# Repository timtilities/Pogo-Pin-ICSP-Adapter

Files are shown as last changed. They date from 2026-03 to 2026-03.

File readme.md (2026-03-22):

Pogo pin ICSP programming adapter

***

The standard 2x3 ICSP header that is usually used for Arduino/Atmel projects is bulky and requires a wide header on the PCB. For decent sized through-hole projects this may be OK, but I do a lot of SMD boards (much easier since you don't have to drill a bunch of holes).  I found lots of different ideas on the web, and decided to use pogo pins.  In addition, I found a great project that didn't require multiple PCBs to stabilize the pogo pins! Unfortunately, I don't remember who's project that was so I can't give them credit. Just keep in mind this idea was not entirely mine, nor is it unique. That being said, here are a couple pics of the raw PCB and the finished products:

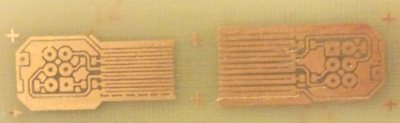
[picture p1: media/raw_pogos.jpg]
raw_pogos
 finished_pogos

There are 2 versions, the first being a "normal" sized board with a pitch of about 1.83mm, the second being a tiny version with a pitch of about 1.27mm. In most cases, I go with the 1.83 pitch board since I can route small traces between the pads. The 1.27mm version is good for those boards with no room to spare, but I have never needed it. The Kicad library only includes the larger 1.83mm pitch footprint. 

Here's an example of using the ICSP pads designed for these pogo adapters:

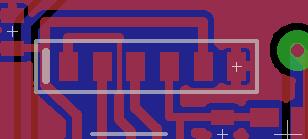
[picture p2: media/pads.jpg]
pads
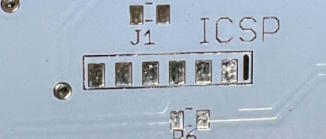
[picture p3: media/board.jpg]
board
 

To assemble the adapter, carefully solder the pogo pins in between the long PCB traces on the board. If done correctly, they should sit right in between the traces and be fairly stable while you solder.  I made the 2 pins on either end slightly longer than the middle pins, but it isn't really necessary.

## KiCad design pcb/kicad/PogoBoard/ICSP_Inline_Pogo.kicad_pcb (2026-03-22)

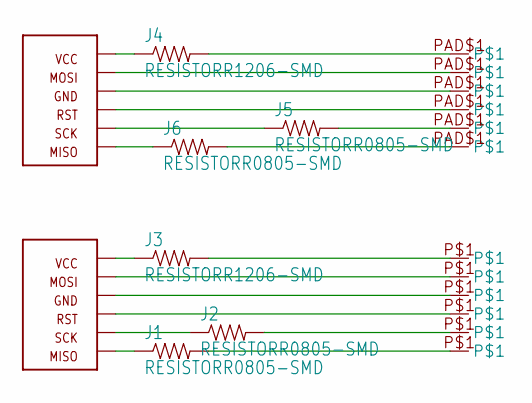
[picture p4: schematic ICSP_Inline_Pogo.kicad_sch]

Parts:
GND0: POGO_PADR50; P50_POGO_PIN
GND1: POGO_PADR75; P75_POGO_PIN
J1, J2, J5, J6: RESISTORR0805-SMD; R0805
J3, J4: RESISTORR1206-SMD; R1206
MISO0: POGO_PADR50; P50_POGO_PIN
MISO1: POGO_PADR75; P75_POGO_PIN
MOSI0: POGO_PADR50; P50_POGO_PIN
MOSI1: POGO_PADR75; P75_POGO_PIN
RST0: POGO_PADR50; P50_POGO_PIN
RST1: POGO_PADR75; P75_POGO_PIN
SCK0: POGO_PADR50; P50_POGO_PIN
SCK1: POGO_PADR75; P75_POGO_PIN
U$1, U$3: AVR_ICSP_6P2X3_THP; AVR_ICSP_2X3_THP
VCC0: POGO_PADR50; P50_POGO_PIN
VCC1: POGO_PADR75; P75_POGO_PIN

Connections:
GND: GND0.P$1, U$3.GND
GND1: GND1.PAD$1, U$1.GND
MISO: J1.1, U$3.MISO
MISO1: J6.2, MISO1.PAD$1
MOSI: MOSI0.P$1, U$3.MOSI
MOSI1: MOSI1.PAD$1, U$1.MOSI
unnamed: J1.2, MISO0.P$1
unnamed: J3.1, U$3.VCC
unnamed: J2.1, U$3.SCK
unnamed: J6.1, U$1.MISO
unnamed: J5.2, SCK1.PAD$1
unnamed: J4.1, U$1.VCC
RST: RST0.P$1, U$3.RST
RST1: RST1.PAD$1, U$1.RST
SCK: J2.2, SCK0.P$1
SCK1: J5.1, U$1.SCK
VCC: J3.2, VCC0.P$1
VCC1: J4.2, VCC1.PAD$1

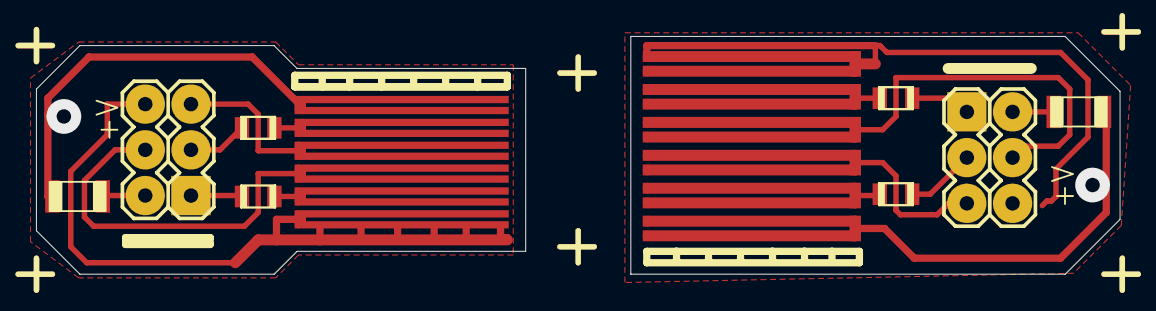
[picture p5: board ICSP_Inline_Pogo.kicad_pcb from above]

Board: 2 copper layers, 60.2 x 13.2 mm, 20 parts (0 on the bottom side), 18 nets.

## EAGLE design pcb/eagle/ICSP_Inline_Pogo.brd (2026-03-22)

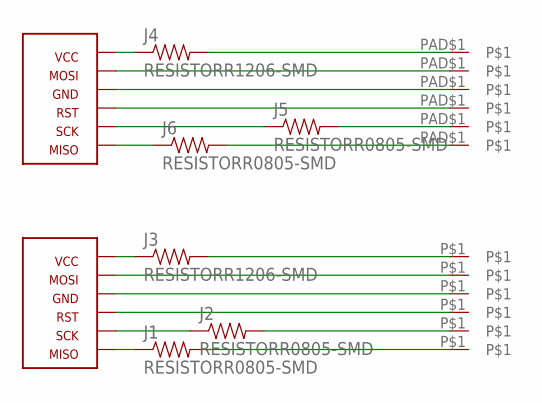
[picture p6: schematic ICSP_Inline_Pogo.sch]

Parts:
GND: POGO_PADR50; P50_POGO_PIN
GND1: POGO_PADR75; P75_POGO_PIN
J1, J2, J5, J6: RESISTORR0805-SMD; R0805
J3, J4: RESISTORR1206-SMD; R1206
MISO: POGO_PADR50; P50_POGO_PIN
MISO1: POGO_PADR75; P75_POGO_PIN
MOSI: POGO_PADR50; P50_POGO_PIN
MOSI1: POGO_PADR75; P75_POGO_PIN
RST: POGO_PADR50; P50_POGO_PIN
RST1: POGO_PADR75; P75_POGO_PIN
SCK: POGO_PADR50; P50_POGO_PIN
SCK1: POGO_PADR75; P75_POGO_PIN
U$1, U$3: AVR_ICSP_6P2X3_THP; AVR_ICSP_2X3_THP
VCC: POGO_PADR50; P50_POGO_PIN
VCC1: POGO_PADR75; P75_POGO_PIN

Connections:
GND: GND.P$1, U$3.GND
GND1: GND1.PAD$1, U$1.GND
MISO: J1.1, U$3.MISO
MISO1: J6.2, MISO1.PAD$1
MOSI: MOSI.P$1, U$3.MOSI
MOSI1: MOSI1.PAD$1, U$1.MOSI
unnamed: J1.2, MISO.P$1
unnamed: J3.1, U$3.VCC
unnamed: J2.1, U$3.SCK
unnamed: J6.1, U$1.MISO
unnamed: J5.2, SCK1.PAD$1
unnamed: J4.1, U$1.VCC
RST: RST.P$1, U$3.RST
RST1: RST1.PAD$1, U$1.RST
SCK: J2.2, SCK.P$1
SCK1: J5.1, U$1.SCK
VCC: J3.2, VCC.P$1
VCC1: J4.2, VCC1.PAD$1

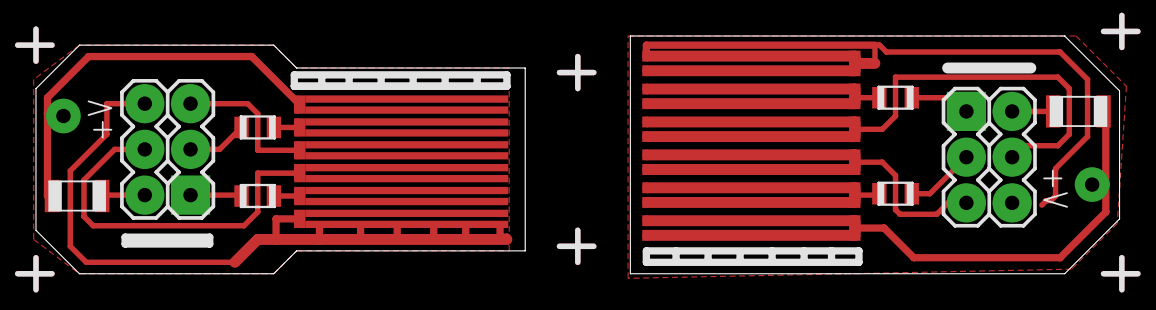
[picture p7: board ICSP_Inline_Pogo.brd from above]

Board: 2 copper layers, 60.2 x 13.2 mm, 20 parts (0 on the bottom side), 18 nets.
